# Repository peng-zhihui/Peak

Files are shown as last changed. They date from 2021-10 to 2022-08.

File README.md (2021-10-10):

## 说明

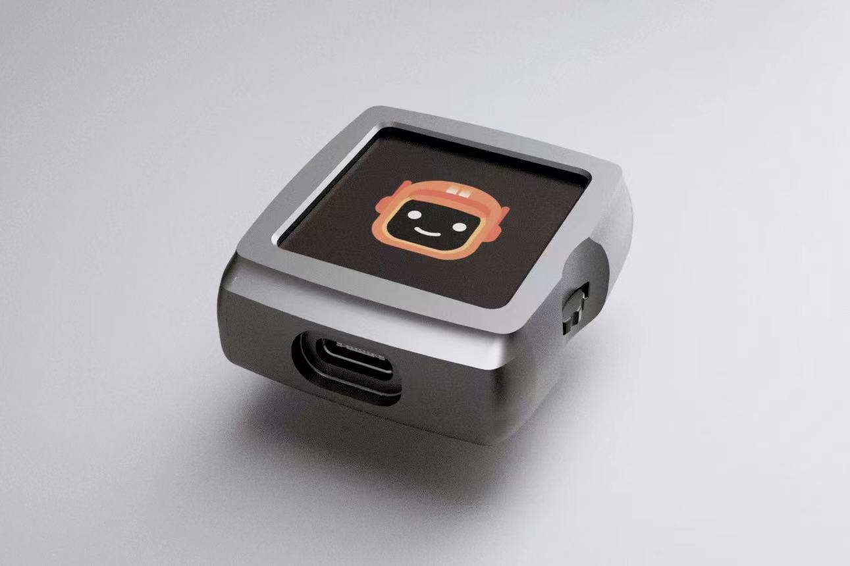
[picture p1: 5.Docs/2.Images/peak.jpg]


> 本项目是一个超迷你的智能小终端，集成LVGL图像框架、MVC框架、消息框架、WiFi蓝牙能力，未来会加入触摸屏支持。可以作为智能控制器用于实现很多应用。
>
> 另外我正在上面实现一个非常小型的3D引擎，可以用于动态显示一些3D模型（就像Dummy示教器中展示的那样）。

非常感谢 https://github.com/FASTSHIFT 开源的X-Track项目，本文是对于X-Track硬件和固件往ESP32平台移植的记录说明。

## 1. 硬件移植

### 关于芯片选型

主要考虑MCU的Flash、SRAM、SPI速度，需要满足以下要求：

* 主频 > 150MHz
* RAM >= 200KB
* FLASH >= 512KB
* SPI速度 >= 50Mbps（60fps刷新率的要求）

> lvgl中需要设置LCD buffer，一般设置为屏幕分辨率大小，在本项目中为240x240x2（因为是16bit色深所以每个像素2字节），算下来至少需要112KB的SRAM。
>
> SPI的CLK速度计算如下：240x240x2x8x60=55.296MHz，因此最好是达到50MHz以上的频率才能保证刷新流畅（实际上不使用DMA传输数据的话帧率会更低）。

经过筛选满足以上要求的MCU，综合考虑成本和购买渠道问题，除了官方项目使用的雅特力AT32F403ACGU7主控外，还有两款是比较合适的：STM32F405RGT6、ESP32。

**对比优缺点如下：**

* STM32F405的主频不如ESP32高且后者为双核；
* 外设方面STM32F405更丰富，也支持使用DMA+SPI驱动屏幕；
* ESP32带WiFi能力，STM32不带；
* ESP32可以直接基于Arduino生态开发，而STM32一般基于HAL库，移植Arduino较麻烦；
* STM32可以使用ST-Link方便调试而ESP32只能通过串口打印log调试。

最终选择**ESP32-PICO-D4**作为移植MCU方案。

## 2. 固件移植

原工程的架构分层设计比较合理，整体软件架构如下图所示，系统由 HAL、Framework 和 APP 三层组成 ：

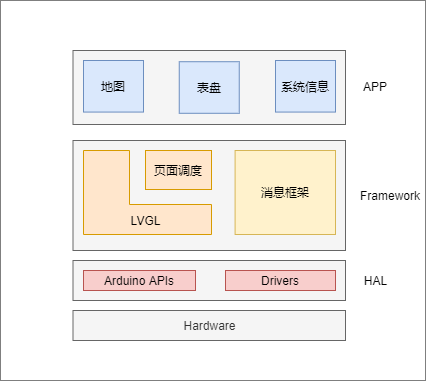
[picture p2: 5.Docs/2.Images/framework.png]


### LVGL 和页面调度

LVGL是开源的嵌入式图形库，其广泛应用嵌入式 GUI 中，提供了基础控件和底层图形渲染能力。

X-TRACK 使用 LVGL 作为图形库，提供用户显示界面，并使用了许多 LVGL 提供的基础控件。例如在地图页面的轨迹显示中使用了 line 控件，地图显示使用了 image 控件，在表盘页面的页面切换选择，使用了 button 控件。由于 LVGL 自带页面管理功能较弱，需要规范页面行为，便于对页面生命周期进行管理。

页面调度器参考 **IOS ViewController** 进行设计，页面生命周期管理流程图如下：

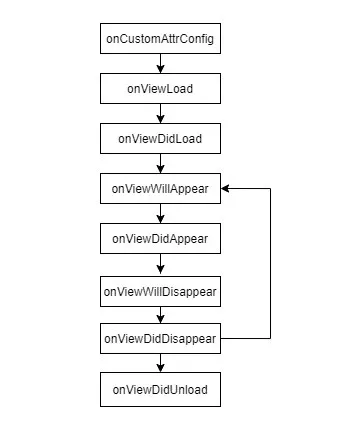
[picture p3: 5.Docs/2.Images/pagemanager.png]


根据页面当前状态，对页面动作进行管理。例如地图页面的加载，在执行 onViewLoad (页面开始加载)时初始化视图和数据；在 onViewDidAppear（页面即将显示） 执行过渡动画，在动画结束时显示地图容器。

在有外部按键事件触发后，依次执行onViewWillDisappear(页面即将消失)、 onViewDidDisappear （页面消失完成）、onViewDidUnload（页面卸载完成）。

### 消息框架

消息框架提供数据的分发和处理。其使用订阅发布机制完成，将 HAL 层的接收到的传感器数据发布，转发给对应的订阅者进行数据处理。

以 GPS 为例，GPS 数据处理节点每秒读取一次卫星数据，然后发起 publish ，由消息框架将 GPS 数据推送给订阅者。在运动数据处理节点中订阅 GPS 数据。在收到 GPS 数据之后，运动数据处理节点根据 GPS 数据计算总里程，平均速度等信息。在表盘页面中，拉取运动数据节点信息，将其显示在表盘页面中。

比如下图为 GPS 数据事件回调函数:

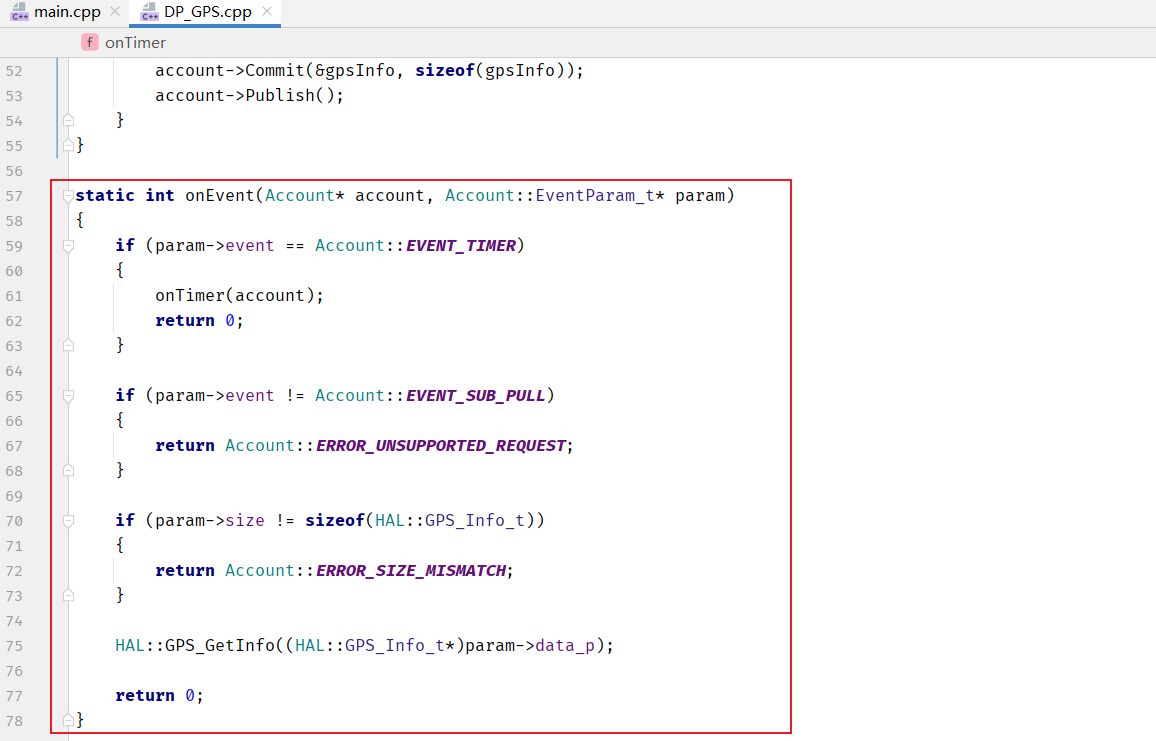
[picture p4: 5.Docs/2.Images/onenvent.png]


### 屏幕移植

具体移植步骤为：

1. 将LVGL（使用版本为`v8.1`）的相关port函数移植到新平台（显示、文件、输入）
2. 实现HAL层的各个文件

> 其中第一步中SD卡文件系统的移植遇到问题是用SD库可以读写，而LVGL的文件操作函数不行，后发现原因是`lv_port_fatfs.cpp`文件中的`lv_fs_drv_t fs_drv`变量需要改为全局/静态变量，原工程中在函数中声明static在CLion编译器下似乎不起作用。

显示的移植涉及到几个配置文件:`Config.h` 、`lv_conf.h`、`User_Setup_Select.h`（`Setup24_ST7789.h`）

首先根据屏幕型号使用`TFT_eSPI`库驱动测试好硬件。

> TFT_eSPI库速度比其他库快，而且其数据类型和LVGL无缝对接。

这个项目中选择`Setup24_ST7789.h`这个配置文件，除了**GPIO**、**屏幕反向**、**像素顺序**设置正确之外，`SPI_FREQUENCY`也是一个很重要的参数，如前面所计算的，为了是的屏幕刷新率达到60Hz，需要设置这个频率高于50MHz。

然而，对于ESP32来说，其具有2个可用的硬件SPI：**HSPI**和**VSPI**。

> SPI0是专用于Flash的缓存，ESP32将连接的SPI Flash设备映射到内存中；SPI1和SPI0 使用相同的硬件线，SPI1用于写入flash芯片。
>
> VSPI是默认的SPI总线，要使用HSPI的话，**需要修改以下代码中的MISO为26**：
>
> ```
>  if(sck == -1 && miso == -1 && mosi == -1 && ss == -1) {
>      _sck = (_spi_num == VSPI) ? SCK : 14;
>      _miso = (_spi_num == VSPI) ? MISO : 12; // 需要改为26
>      _mosi = (_spi_num == VSPI) ? MOSI : 13;
>      _ss = (_spi_num == VSPI) ? SS : 15;
> ```
>
> 这是因为，HSPI的默认MISO引脚是12，而12在ESP32中是用于上电时设置flash电平的，上电之前上拉会导致芯片无法启动，因此我们将默认的引脚替换为26或其他引脚。

由数据手册可知，ESP32的SPI时钟是由80MHz的`APB_CLK`时钟信号分频而来，因此最高支持的频率为80MHz，如果分频的话，库函数会自动选择分配系数来获得最接近于设定频率的整数倍系数。

> **注意**，只有在使用IOMUX时才能获得最高的SPI频率，如果SPI采用GPIO矩阵，则最大频率会限制在26.6MHz。
>
> IOMUX指的是不使用IO-Matrix的映射功能，而是使用默认的MISO、MOSI、CLK引脚，也就是如下图：
>
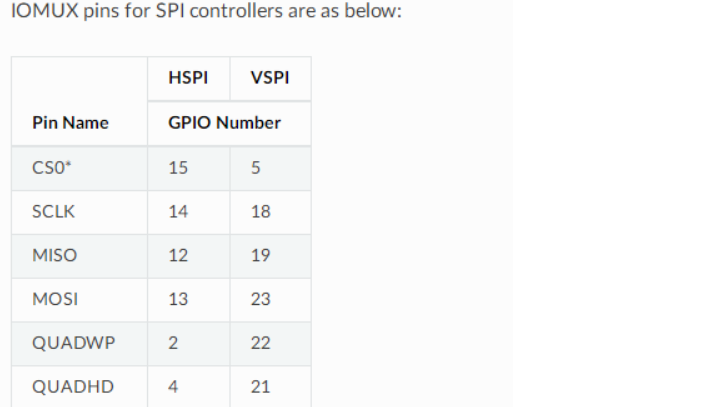
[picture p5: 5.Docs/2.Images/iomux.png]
> 

屏幕驱动验证完成后，配置LVGL的相关初始化函数，其中`lv_conf.h`的配置有几点值得注意的：

* **LV_MEM_SIZE的设置**

  在Arduino环境中LVGL默认定义LV_MEM_CUSTOM=0，即不使用标准库中的*malloc*等内存分配函数，而是封装了一个*lv_mem_alloc()*函数用于内存申请。这个函数的原理其实是**先在编译的时候申请一块`LV_MEM_SIZE`大小的数组内存，然后在后面使用*lv_mem_alloc()*函数的时候，从这块内存中进行分配。**

  因此，`LV_MEM_SIZE`设置的内存大小是在bss段分配的，**这个数值设置过大的话会导致编译链接阶段报错内存不足。**

  > 经测试设置16K就足够了，因此代码中该值为`(16 * 1024U)` 。
  >
  > 如果想在后面屏幕buffer中使用这块内存进行分配，那就需要设置大一点，但是ESP32的Arduino框架中对于申请静态内存的尺寸有限制，因此我们并不使用这里的内存，而是到时候用*malloc()*函动态数申请。

* **`lv_disp_draw_buf_init`函数中的屏幕buffer设置**

  这个buffer可以设置为单buffer或者双buffer，但是双buffer只在使用DMA传输数据的时候可以起作用（刷新缓存和传输数据并行），因此这里只用单buffer。

  理论上buffer的尺寸等于屏幕分辨率是最理想的，可以保证一次刷新整个屏幕，~~但是由于ESP32的内存大小限制，本代码中最大只能设置为屏幕分辨率的一半。~~

  > 最早HoloCubic的代码中并未注意到这一设置，buffer只设置为了240x10，因此导致画面刷新缓慢且有撕裂感。
  >
  > 关于ESP32内存申请的限制，由于能用的内存实际只有大概300KB，而屏幕完整buffer需要112KB，因此很难在内存中找到连续的那么大片空间，~~经测试不管是用静态变量申请还是malloc动态申请，都无法成功，因此只能设置为一半大小的buffer。~~
  >
  > 在ESP32-PICO-D4上测试发现，如果新建空白工程再用`ESP.getMaxAllocHeap()`，得到的可用空间是略大于115200B的，但是加入`lvgl_init()`代码之后就不足115200了，因此修改`lvgl_init()`函数代码，把`lv_mem_init`函数中static 变量申请的内存改为动态malloc，即可解决buffer问题。
  >
  > 引起该问题的原因是，ESP32有多块内存可以映射为dataRAM，总大小是300KB左右，但它们之间是不连续的，最大的一块刚好略大于115200。如果在代码中事先编译的时候分配内存占用了这一块（声明了static变量），或者运行的时候在LVGL申请屏幕buffer之前先被其他地方申请了该块内存导致连续可用heap小于115200，那么屏幕buffer就无法申请成功。因此解决方案是先在代码中将这块最大的heap申请下来给屏幕buffer，再运行其他初始化代码即可完美解决。
  
  关于ESP32的内存模型更多信息，可以参考文章末尾链接的几篇文章分析。

## 参考链接 

* [LVGL](https://github.com/lvgl/lvgl)
* [Bing Maps Tile System](https://docs.microsoft.com/en-us/bingmaps/articles/bing-maps-tile-system?redirectedfrom=MSDN)
* [IOS ViewController](https://developer.apple.com/documentation/uikit/uiviewcontroller)
* [ESP32之软件SPI驱动及SPI、HSPI和VSPI的理解](https://blog.csdn.net/jdsnpgxj/article/details/100013357)
* [ESP32 程序的内存模型](https://zhuanlan.zhihu.com/p/345915256)
* [Heap Memory Allocation](https://docs.espressif.com/projects/esp-idf/en/latest/esp32/api-reference/system/mem_alloc.html)
* [Error: region `dram0_0_seg' overflowed by 31632 bytes](https://www.esp32.com/viewtopic.php?t=7131)
* [[ESP32] ld: region `dram0_0_seg’ overflowed by 156768 bytes](https://community.platformio.org/t/esp32-ld-region-dram0-0-seg-overflowed-by-156768-bytes/18753)

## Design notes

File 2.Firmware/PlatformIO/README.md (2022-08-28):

Peak-ESP32-fw(6050)      修改9250程序为6050

上一个版本在最新的platformio框架会报FreeRTOS路径错误和sd库中定义错误

由于platformio框架版本问题会报的错误解决方法：

HAL.h 文件  \#include "FreeRTOS.h"改为 \#include "FreeRTOS/FreeRTOS.h"

lib/SD/src/sd_diskio.cpp   添加头文件 \#include "diskio_impl.h"

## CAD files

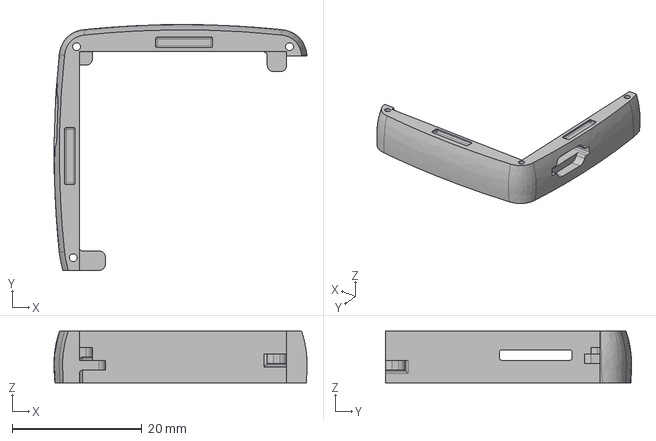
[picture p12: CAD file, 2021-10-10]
4.Model/侧件.step
38.9 x 37.8 x 8.00 mm

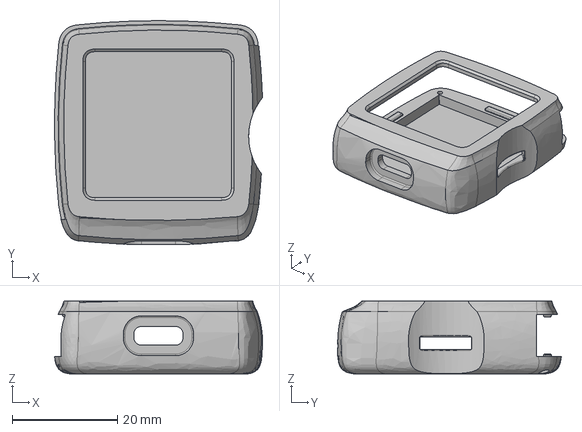
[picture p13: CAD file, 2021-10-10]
4.Model/主件.step
39.5 x 42.5 x 13.8 mm

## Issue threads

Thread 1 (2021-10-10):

关于元器件推荐咨询以及3D模型

zhiwenwu, 2021-10-10:
大佬，有推荐的元器件链接吗？还有大佬的3D建模用的是哪款软件吗？

peng-zhihui, 2021-10-10:
是说元器件库吗？我一般都是自己画的

peng-zhihui, 2021-10-10:
> 这个是8PIN接插屏幕吗？找了好长时间。有老铁有推荐链接吗？

https://detail.tmall.com/item.htm?id=607394513826&_u=a2hql9gc2718

mascg, 2021-10-10:
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

https://github.com/FASTSHIFT/X-TRACK/tree/main/Hardware
X-TRACK 用的这个屏幕，应该可以参考下

peng-zhihui, 2021-10-10:
就是上面这款

zhiwenwu, 2021-10-14:
> 就是上面这款
https://github.com/FASTSHIFT/X-TRACK/tree/main/Hardware
大佬，我按照这块屏幕购买的硬件，发现这款不是FFC/FPC接口的，请问您这8PIN的硬件，是有增加转接板吗？如果没有转接板的话，能帮忙看下具体购买链接？

Closed 2021-10-10.

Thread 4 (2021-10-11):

Peak硬件电路设计问题

captain-zhang, 2021-10-11:
彭兄好，今天看了peak的电路设计，我鸡蛋里面挑骨头，提点建议。在电源模块的设计中，锂电池充电芯片的输出既为锂电池充电，又为整个电路供电，这样设计会有问题。充电时既会影响电池端电压又会分充电电流，严重影响充电芯片对电池状态的判断。这种情况下锂电池一般无法充满电。因此设计中应该在外部供电时，切断电池与后续电路的连接，此时整个电路的供电应该由充电芯片的前端电源提供。

SuperWangRong, 2021-10-21:
> 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
>
> 这是我结合稚晖君的电路以及b站郭天祥老师的锂电池充电电路改动后的，是可以实现供电切换的，欢迎指正 郭天祥老师此部分电路视频链接：https://www.bilibili.com/video/BV17Q4y1k78s?spm_id_from=333.999.0.0

Q4和R7是不是可以去掉啊？

SuperWangRong, 2021-10-21:
> 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
>
> 这是我结合稚晖君的电路以及b站郭天祥老师的锂电池充电电路改动后的，是可以实现供电切换的，欢迎指正 郭天祥老师此部分电路视频链接：https://www.bilibili.com/video/BV17Q4y1k78s?spm_id_from=333.999.0.0

还有U1的3号脚应该接VCC_SYS吧？

SuperWangRong, 2021-11-02:
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
我实测发现CHG_DET处的上拉电阻为10K时无法将该点拉至3.3V，实测只有1.9V左右，此时MCU检测为低电平，显示屏的电池图标会为动态充电样式，将电阻改成1K上拉后，CHG_DET测量下来为2.5V左右，MCU检测为高电平，显示屏的电池图标状态为静止状态，这时显示是正确的，，，，，另外BAT_DET的分压电阻网络的电源我改成了VABT_IN，附图是我更新后的电路，可供后来人参考，如有错误或不完善处还请帮忙指出，多谢~

Purvirs, 2022-02-04:
> 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 我实测发现CHG_DET处的上拉电阻为10K时无法将该点拉至3.3V，实测只有1.9V左右，此时MCU检测为低电平，显示屏的电池图标会为动态充电样式，将电阻改成1K上拉后，CHG_DET测量下来为2.5V左右，MCU检测为高电平，显示屏的电池图标状态为静止状态，这时显示是正确的，，，，，另外BAT_DET的分压电阻网络的电源我改成了VABT_IN，附图是我更新后的电路，可供后来人参考，如有错误或不完善处还请帮忙指出，多谢~

----------------
多谢改进，根据手册和实际调试发现，73831在充电结束之后会拉高STAT脚，电压约等于VBUS-0.4，此时输入口灌入电压高于3.3V会造成AD采样工作不正常，对芯片的稳定工作也是一个影响。此处最好转换电平。

zhaoyang6, 2022-04-19:
关于73831在充电结束后，拉高STAT引脚，后输出电压约等于(VBUS-0.4)V，而ESP32的管脚电压最高是（VDD+0.3）V。在设计中使用的电池是VBUS=3.7V，VDD=3.3V,这样计算来，STAT引脚输出电压约是3.3V, 管脚电压最高是3.6V, 在这样小的差距下，是否可能会有损坏芯片的情况？

Purvirs, 2022-04-30:
> 关于73831在充电结束后，拉高STAT引脚，后输出电压约等于(VBUS-0.4)V，而ESP32的管脚电压最高是（VDD+0.3）V。在设计中使用的电池是VBUS=3.7V，VDD=3.3V,这样计算来，STAT引脚输出电压约是3.3V, 管脚电压最高是3.6V, 在这样小的差距下，是否可能会有损坏芯片的情况？

注意上述讨论，是基于做了电源自动切换，在充电时VBUS几乎等于USB供电电压，约为5V，实际灌入到ESP32电压是4点几伏。
针对这个问题不才改了一版仅供参考
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

geekfuns, 2022-08-17:
> 这里确实是一个设计失误，感谢指出

实际上使用一篇带动态路径管理的电源芯片就好了，在我的设计中使用了ETA6002，完全满足需求，自动切换主备电并且具备电池充电功能

juring, 2022-12-02:
> 73831在充电结束之后会拉高STAT脚，电压约等于VBUS-0.4，此时输入口灌入电压高于3.3V会造成AD采样工作不正常，对芯片的稳定工作也是一个影响。此处最好转换电平。

是不是换成 73832 就行了。

Purvirs, 2023-02-11:
>

换成17832也不能解决这个问题

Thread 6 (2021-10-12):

关于线程同步

zye1996, 2021-10-12:
Hi Zhihui, 目前我把固件移植到了m5stack上，运行还没有出现问题。

我看到ESP32这个版本是多线程的，lvgl事件循环单独在一个线程里轮询控件状态，page manager在loop线程也会创建删除控件，这样在复杂情况下需要做线程同步吗？

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

peng-zhihui, 2021-10-12:
是需要的，考虑使用FreeRTOS的信号量同步。

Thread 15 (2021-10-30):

请教一下，稚晖君你的开发环境是什么？

FlyyingPiggy2020, 2021-10-30:
不知道稚晖君，你是用什么IDE开发的ESP32程序？是在Windows平台还是别的平台？
我现在对着这份代码，不知道怎么去编译它。。

peng-zhihui, 2021-10-30:
了解一下platformio，windows下编译，安装好环境直接用vscode打开项目文件夹就能编译了

发自我的iPhone

------------------ 原始邮件 ------------------
发件人: BeeeeeeLazy ***@***.***&gt;
发送时间: 2021年10月30日 15:21
收件人: peng-zhihui/Peak ***@***.***&gt;
抄送: Subscribed ***@***.***&gt;
主题: 回复：[peng-zhihui/Peak] 请教一下，稚晖君你的开发环境是什么？ (Issue #15)

Closed 2023-11-14.

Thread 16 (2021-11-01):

关于CON1 引脚引出问题

HanfG, 2021-11-01:
MCU的 GPIO5, GPIO10, GPIO19, GPIO32, GPIO33 五个引脚由CON1引出，其中GPIO32, 33已被I2C总线使用，目前线上有MPU6050，引出可以用于I2C 设备扩展；其余3个IO引脚应该是用于普通IO扩展吧，我看到芯片的GPIO9目前是悬空状态，是不是可以考虑用GPIO9替换GPIO5吗？这样可以实现MCU的UART 1信号引出 增强扩展性，也可以避免意外情况下GPIO5拉低导致MCU无法正常启动。
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

peng-zhihui, 2021-11-01:
esp32是带gpio-matrix的，差不多所有引脚都能自由映射

发自我的iPhone

------------------ 原始邮件 ------------------
发件人: HanfG ***@***.***&gt;
发送时间: 2021年11月1日 16:47
收件人: peng-zhihui/Peak ***@***.***&gt;
抄送: Subscribed ***@***.***&gt;
主题: 回复：[peng-zhihui/Peak] 关于CON1 引脚引出问题 (Issue #16)

MCU的 GPIO5, GPIO10, GPIO19, GPIO32, GPIO33 五个引脚由CON1引出，其中GPIO32, 33已被I2C使用，目前线上由MPU6050，引出可以用于I2C 设备扩展；其余3个IO引脚应该是用于普通IO扩展吧，芯片的GPIO9目前是悬空状态，可以考虑用GPIO9替换GPIO5吗？这样可以实现MCU的UART 1信号引出 增强扩展性，也可以避免意外情况下GPIO5拉低导致MCU无法正常启动。

—
You are receiving this because you are subscribed to this thread.
Reply to this email directly, view it on GitHub, or unsubscribe.
Triage notifications on the go with GitHub Mobile for iOS or Android.

HanfG, 2021-11-01:
好的，学到了，感谢> esp32是带gpio-matrix的，差不多所有引脚都能自由映射
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

Closed 2021-11-02.

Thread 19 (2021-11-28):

页面切换到3D 正方形后回不了SystemInfos页面

bt5-coder, 2021-11-28:
zhihui你好，

感谢你的创作和工作，我已经把软件移植到M5 Stack，目前遇到一个小问题，不知道是不是一个Bug。
页面管理从SystemInfos 切到 Scene 3D在切回到SystemInfos， 再次按下按钮切到 Scene 3D之后，无论怎么操作都切不回SystemInfos 界面，界面一直是Sense 3D的图像，但此时按键log告诉我已经在SystemInfos even里面了。

我单独拉出template和Scene 3D，按照Push - > Pop操作，一样存在问题 ，切一次页面后，停留在template，无法再切入Scene 3D。
不知道是不是页面管理的框架有问题。
本来想再模拟器上来验证，编译了你的代码，好多问题，应该是路径有问题。

以上信息供你参考。

bt5-coder, 2021-12-05:
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
我在模拟器上也可以复现，错误显示见上图。

spdffxyp, 2023-09-26:
最近也遇到了整个问题，解决方案如下：

在Scene3DView::Create函数中删除
lv_indev_set_group(lv_get_indev(LV_INDEV_TYPE_ENCODER), ui.group);

在Scene3D::onViewWillAppear函数中增加
lv_indev_set_group(lv_get_indev(LV_INDEV_TYPE_ENCODER), View.ui.group);

zhihui的Scene3D类是个半成品，里面还有别的坑，还在学习中。

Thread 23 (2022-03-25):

采用httpCilent获取天气状况的问题

pockrt-m, 2022-03-25:
在复现peak项目时发现，设备能够成功连接wifi，但获取天气时报错：
`_handle_error(): [start_ssl_client():205]: (-32512) SSL - Memory allocation failed`；
将屏幕分得的缓存尽可能减小后又能成功获取天气数据，判断可能是内存分配问题导致无法正常进行ssl_cilent，但不知道该如何进行修改，请各位大佬提提意见~

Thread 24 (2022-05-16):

下载的工程编译后报错，提示没有freertos文件 还有fat文件系统也有错误。

givemethree, 2022-05-16:
1.freertos  报错内容
******************************************************************

 #include "FreeRTOS.h"
          ^~~~~~~~~~~~
compilation terminated.
In file included from src/App/Accounts/ACT_IMU.cpp:2:
src/HAL/HAL.h:9:10: fatal error: FreeRTOS.h: No such file or directory

2.注释freertos文件后编译报fat 错误。

lib/SD/src/sd_diskio.cpp:825:18: error: 'ff_diskio_impl_t' does not name a type
     static const ff_diskio_impl_t sd_impl = {
                  ^~~~~~~~~~~~~~~~
lib/SD/src/sd_diskio.cpp:832:31: error: 'sd_impl' was not declared in this scope
     ff_diskio_register(pdrv, &sd_impl);
                               ^~~~~~~
lib/SD/src/sd_diskio.cpp:832:31: note: suggested alternative: 'fdiml'
     ff_diskio_register(pdrv, &sd_impl);
                               ^~~~~~~
                               fdiml
lib/SD/src/sd_diskio.cpp:832:5: error: 'ff_diskio_register' was not declared in this scope
     ff_diskio_register(pdrv, &sd_impl);
     ^~~~~~~~~~~~~~~~~~
lib/SD/src/sd_diskio.cpp:832:5: note: suggested alternative: 'lv_disp_drv_register'
     ff_diskio_register(pdrv, &sd_impl);
     ^~~~~~~~~~~~~~~~~~
     lv_disp_drv_register
*** [.pio\build\pico32\libbbe\SD\sd_diskio.cpp.o] Error 1

givemethree, 2022-05-21:
platform 安装方式的问题，重新按照标准安装方式安装platformio后 再编译就没问题了
标准安装方式： https://blog.csdn.net/JR_Smmon/article/details/120856365

givemethree, 2022-05-21:
问题关闭

jiuwei000, 2022-06-18:
> platform 安装方式的问题，重新按照标准安装方式安装platformio后 再编译就没问题了 标准安装方式： https://blog.csdn.net/JR_Smmon/article/details/120856365

我遇到了和你一样的问题，请问解决的关键点就是按这篇博文写的那样做么？我照着做了之后仍然报错没有freertos头文件。。。

FChong96, 2022-08-04:
我也遇到了相同的问题，缺少头文件，如果注释掉的话会出fat 错误。重装了Platform并没有解决问题。

jiuwei000, 2022-08-04:
>

问题解决了，esp32的platform用3.5版本

FChong96, 2022-08-04:
> >
>
> 问题解决了，esp32的platform用3.5版本
我也试一下，freertos头文件需要注释掉吗

MXuanZero, 2022-08-22:
> >
>
> 解决了，esp32的平台问题用3.5版本

请教一下，怎么安装3.5版本？我没找到相关的安装途径。
谢谢！

MXuanZero, 2022-08-22:
问题解决了，上面的解决方法试了一遍不太行，如果有人没解决的话可以去看我这个[issues](https://github.com/peng-zhihui/Peak/issues/28#issuecomment-1222158709)。
https://github.com/peng-zhihui/Peak/issues/28#issuecomment-1222158709

Closed 2022-05-21.

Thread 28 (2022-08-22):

请教一下各位，VS Code 打开工程后找不到 FreeRTOS.h 该怎么解决？

MXuanZero, 2022-08-22:
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
如图，VS Code 打开工程后找不到 FreeRTOS.h 文件，这是环境的问题吗？我该怎么解决？

另外，我用 CLion 编译项目时发生了如下错误。感觉我的 PlatformIO 好像少了什么文件一样，但我重装了两三次都存在这个问题？请问有办法解决吗？
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

MXuanZero, 2022-08-22:
花了一下午时间终于解决了，我们将以下代码复制到 diskio.h 的第 12 行。这个地方最初应该只有一行 `typedef BYTE DSTATUS;`。

```c
/* Status of Disk Functions */
/* This type MUST be 8 bit */
typedef unsigned char	BYTE;
typedef BYTE			DSTATUS;	//最初
/* These types MUST be 16 bit */
typedef short			SHORT;
typedef unsigned short	WORD;
typedef unsigned short	WCHAR;

/* These types MUST be 16 bit or 32 bit */
typedef int				INT;
typedef unsigned int	UINT;

/* These types MUST be 32 bit */
typedef long			LONG;
typedef uint32_t		DWORD;
```

**补充1：**倘若无法找到 FreeRTOS.h，我们只是要将工程中出现 FreeRTOS.h 的地方改成 freertos/FreeRTOS.h 就行了。

**补充2：**倘若出现类似于 error: 'ff_diskio_get_drive' was not declared in this scope 这种 FATFS 系统的函数找不到的错误。我们要将 \#include "diskio_impl.h" 添加到 sd_diskio.cpp 中。

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

==**请注意：**以上方法虽然可以成功编译，但我并没有烧到板子上去，所以也不知道能不能成！如果有人成功的话麻烦告知一下。==

MXuanZero, 2022-08-22:
花了一下午时间终于解决了，我们将以下代码复制到 diskio.h 的第 12 行。这个地方最初应该只有一行 `typedef BYTE DSTATUS;`。

```c
/* Status of Disk Functions */
/* This type MUST be 8 bit */
typedef unsigned char	BYTE;
typedef BYTE			DSTATUS;	//最初
/* These types MUST be 16 bit */
typedef short			SHORT;
typedef unsigned short	WORD;
typedef unsigned short	WCHAR;

/* These types MUST be 16 bit or 32 bit */
typedef int				INT;
typedef unsigned int	UINT;

/* These types MUST be 32 bit */
typedef long			LONG;
typedef uint32_t		DWORD;
```

**补充1：**倘若无法找到 FreeRTOS.h，我们只是要将工程中出现 FreeRTOS.h 的地方改成 freertos/FreeRTOS.h 就行了。

**补充2：**倘若出现类似于 error: 'ff_diskio_get_drive' was not declared in this scope 这种 FATFS 系统的函数找不到的错误。我们要将 \#include "diskio_impl.h" 添加到 sd_diskio.cpp 中。

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

==**请注意：**以上方法虽然可以成功编译，但我并没有烧到板子上去，所以也不知道能不能成！如果有人成功的话麻烦告知一下。==

LiangTY, 2022-08-27:
DSTATUS、DWORD等问题，可以把#include "ff.h"放在#include "diskio.h"前面，让ff.h先编译即可。
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

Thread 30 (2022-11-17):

有没有遇到过这个问题朋友，[ 1316][E][esp32-hal-ledc.c:75] ledcSetup(): ledc setup failed!

compilerM, 2022-11-17:
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

0clock, 2023-02-10:
我也遇到了相同的问题：
```
rst:0xb (TGWDT_CPU_RESET),boot:0x1b (SPI_FAST_FLASH_BOOT)
configsip: 188777542, SPIWP:0xee
clk_drv:0x00,q_drv:0x00,d_drv:0x00,cs0_drv:0x00,hd_drv:0x00,wp_drv:0x00
mode:DIO, clock div:2
load:0x3fff0030,len:1184
load:0x40078000,len:13132
load:0x40080400,len:3036
entry 0x400805e4
[littleVisual]
Version: v1.0
Author: PZH
Power: Waiting...
Power: ON
E (1024) ledc: freq_hz=0 duty_resolution=8
[  1028][E][esp32-hal-ledc.c:75] ledcSetup(): ledc setup failed!
[  1029][E][esp32-hal-gpio.c:102] __pinMode(): Invalid pin selected
E (1029) gpio: gpio_set_level(226): GPIO output gpio_num error
[  1039][E][esp32-hal-gpio.c:102] __pinMode(): Invalid pin selected
E (1041) gpio: gpio_set_level(226): GPIO output gpio_num error
[Warn]	(1.620, +1620)	 lv_init: Style sanity checks are enabled that uses more RAM 	(in lv_obj.c line #163)
```

jxltom, 2023-09-06:
屏幕能点亮吗？

zhaoc9527, 2023-11-28:
我也遇到了，屏幕没反应 怎么办呢

zhaoc9527, 2023-11-29:
> 在paltforformio.ini 文件中指定使用3.5.0的版本 platform = espressif32@~3.5.0

谢谢，这个错误好了 屏幕不亮，报错[Error] (1.477, +1477)   sdcard_mount: f_mount failed: (13) There is no valid FAT volume

SD卡使FAT32格式的，16GB

请问这个使什么原因呢

zhaoc9527, 2023-11-29:
![Uploading 微信图片_20231129115343.png…]()

zhaoc9527, 2023-11-29:
![Uploading 微信图片_20231129115343.png…]()

txp666, 2023-11-29:
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

[littleVisual-ESP32-fw(6050).zip](https://github.com/peng-zhihui/Peak/files/13496020/littleVisual-ESP32-fw.6050.zip)
用这个程序，有问题的话请检查硬件焊接或者sd卡

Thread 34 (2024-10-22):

IntegerDivideByZero导致的系统崩溃重启问题

Raphtalia-chann, 2024-10-22:
稚晖君您好！想请教一下在切换页面时经常会出现IMU错误：
`[E][esp32-hal-i2c.c:1434] i2cCheckLineState(): Bus Invalid State, TwoWire() Can't init sda=1, scl=1`
检查焊接应该没有问题，停在IMU或其他任何页面不动又不会报错，但出现这个报错一般伴随着
`Guru Meditation Error: Core  0 panic'ed (IntegerDivideByZero). Exception was unhandled.`
直接导致系统崩溃重启，使用的是MPU6050，以下是完整错误日志：
```
[E][esp32-hal-i2c.c:1434] i2cCheckLineState(): Bus Invalid State, TwoWire() Can't init sda=1, scl=1
[E][esp32-hal-i2c.c:1434] i2cCheckLineState(): Bus Invalid State, TwoWire() Can't init sda=1, scl=1
[E][esp32-hal-i2c.c:1434] i2cCheckLineState(): Bus Invalid State, TwoWire() Can't init sda=1, scl=1
Guru Meditation Error: Core  0 panic'ed (IntegerDivideByZero). Exception was unhandled.
Core 0 register dump:
PC      : 0x400d3140  PS      : 0x00060130  A0      : 0x800d2d1b  A1      : 0x3fffbbb0
A2      : 0x3ffdf7b8  A3      : 0x3ffdbd2c  A4      : 0x000000ed  A5      : 0x0000006e
A6      : 0x00000000  A7      : 0x00000040  A8      : 0x00003fff  A9      : 0xffff5884
A10     : 0x00000000  A11     : 0xfff3f475  A12     : 0xfffff3c0  A13     : 0x3f40054c
A14     : 0x3ffdf844  A15     : 0x00000008  SAR     : 0x0000000a  EXCCAUSE: 0x00000006
EXCVADDR: 0x00000000  LBEG    : 0x400d30c0  LEND    : 0x400d3152  LCOUNT  : 0x00000001

ELF file SHA256: 0000000000000000

Backtrace: 0x400d3140:0x3fffbbb0 0x400d2d18:0x3fffbc90 0x400d2d25:0x3fffbcb0 0x400e8646:0x3fffbcd0 0x400d78e7:0x3fffbd00 0x4009099a:0x3fffbd20
```

Rebooting...

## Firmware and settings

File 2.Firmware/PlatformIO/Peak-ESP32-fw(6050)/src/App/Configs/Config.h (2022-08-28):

#ifndef __CONFIG_H
#define __CONFIG_H

/*=========================
   Application configuration
 *=========================*/

#define CONFIG_SYSTEM_SAVE_FILE_PATH          "S:/SystemSave.json"
#define CONFIG_SYSTEM_LANGUAGE_DEFAULT        {'e','n','-','G','B'}
#define CONFIG_SYSTEM_GMT_OFFSET_DEFAULT      8 // GMT+ 8

#define CONFIG_WEIGHT_DEFAULT                 65 // kg

#define CONFIG_GPS_REFR_PERIOD                1000 // ms
#define CONFIG_GPS_LNG_DEFAULT                116.391332
#define CONFIG_GPS_LAT_DEFAULT                39.907415

#define CONFIG_TRACK_FILTER_OFFSET_THRESHOLD  2 // pixel
#define CONFIG_TRACK_RECORD_FILE_DIR_NAME     "Track"

#define CONFIG_MAP_USE_WGS84_DEFAULT          false

#define CONFIG_MAP_DIR_PATH                   {'/','M','A','P'}//"/MAP"

#define CONFIG_ARROW_THEME_DEFAULT            "default"

#define CONFIG_LIVE_MAP_LEVEL_DEFAULT         16
#define CONFIG_LIVE_MAP_VIEW_WIDTH            LV_HOR_RES
#define CONFIG_LIVE_MAP_VIEW_HEIGHT           LV_VER_RES

/* Simulator */
#define CONFIG_TRACK_VIRTUAL_GPX_FILE_PATH    "S:/TRK_20210801_203324.gpx"

/*=========================
   Hardware Configuration
 *=========================*/

#define NULL_PIN                    PD0

/* Screen */
#define CONFIG_SCREEN_CS_PIN        PB0
#define CONFIG_SCREEN_DC_PIN        PA4
#define CONFIG_SCREEN_RST_PIN       PA6
#define CONFIG_SCREEN_SCK_PIN       PA5
#define CONFIG_SCREEN_MOSI_PIN      PA7
#define CONFIG_SCREEN_BLK_PIN       12

#define CONFIG_SCREEN_HOR_RES       240
#define CONFIG_SCREEN_VER_RES       240
#define CONFIG_SCREEN_BUFFER_SIZE   (CONFIG_SCREEN_HOR_RES * CONFIG_SCREEN_VER_RES /2)

/* Battery */
#define CONFIG_BAT_DET_PIN          37
#define CONFIG_BAT_CHG_DET_PIN      38

/* Buzzer */
#define CONFIG_BUZZ_PIN             25
#define CONFIG_BUZZ_CHANNEL         2
#define CONFIG_SOUND_ENABLE_DEFAULT true

/* IMU */
#define CONFIG_IMU_INT1_PIN         32
#define CONFIG_IMU_INT2_PIN         33

/* I2C */
#define CONFIG_MCU_SDA_PIN          32
#define CONFIG_MCU_SCL_PIN          33

/* Encoder */
#define CONFIG_ENCODER_B_PIN        34
#define CONFIG_ENCODER_A_PIN        35
#define CONFIG_ENCODER_PUSH_PIN     27

/* Power */
#define CONFIG_POWER_EN_PIN         21

/* Debug USART */
#define CONFIG_DEBUG_SERIAL         Serial

/* SD CARD */
#define CONFIG_SD_SPI               SPI_SD
#define CONFIG_SD_CD_PIN            -1
#define CONFIG_SD_MOSI_PIN          PB15
#define CONFIG_SD_MISO_PIN          PB14
#define CONFIG_SD_SCK_PIN           PB13
#define CONFIG_SD_CS_PIN            15
#define CONFIG_SD_DET_PIN           22

/* Stack Info */
#define CONFIG_USE_STACK_INFO       0

#endif

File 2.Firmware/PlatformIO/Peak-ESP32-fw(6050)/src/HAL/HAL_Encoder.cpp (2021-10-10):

#include "HAL/HAL.h"
#include "App/Utils/ButtonEvent/ButtonEvent.h"
#include "App/Accounts/Account_Master.h"

static ButtonEvent EncoderPush(5000);

static bool EncoderEnable = true;
static volatile int16_t EncoderDiff = 0;
static bool EncoderDiffDisable = false;

Account* actEncoder;

static void Encoder_IrqHandler()
{
    if (!EncoderEnable || EncoderDiffDisable)
    {
        return;
    }

    static volatile int count, countLast;
    static volatile uint8_t a0, b0;
    static volatile uint8_t ab0;
    uint8_t a = digitalRead(CONFIG_ENCODER_A_PIN);
    uint8_t b = digitalRead(CONFIG_ENCODER_B_PIN);
    if (a != a0)
    {
        a0 = a;
        if (b != b0)
        {
            b0 = b;
            count += ((a == b) ? 1 : -1);
            if ((a == b) != ab0)
            {
                count += ((a == b) ? 1 : -1);
            }
            ab0 = (a == b);
        }
    }

    if (count != countLast)
    {
        EncoderDiff += (count - countLast) > 0 ? 1 : -1;
        countLast = count;
    }
}

static void Encoder_PushHandler(ButtonEvent* btn, int event)
{
    if (event == ButtonEvent::EVENT_PRESSED)
    {
        HAL::Buzz_Tone(500, 20);
        EncoderDiffDisable = true;
    } else if (event == ButtonEvent::EVENT_RELEASED)
    {
        HAL::Buzz_Tone(700, 20);
        EncoderDiffDisable = false;
    } else if (event == ButtonEvent::EVENT_LONG_PRESSED)
    {
        HAL::Audio_PlayMusic("Shutdown");
        HAL::Power_Shutdown();
    }
}

static void Encoder_RotateHandler(int16_t diff)
{
    HAL::Buzz_Tone(300, 5);

    actEncoder->Commit((const void*) &diff, sizeof(int16_t));
    actEncoder->Publish();
}

void HAL::Encoder_Init()
{
    pinMode(CONFIG_ENCODER_A_PIN, INPUT_PULLUP);
    pinMode(CONFIG_ENCODER_B_PIN, INPUT_PULLUP);
    pinMode(CONFIG_ENCODER_PUSH_PIN, INPUT_PULLUP);

    attachInterrupt(CONFIG_ENCODER_A_PIN, Encoder_IrqHandler, CHANGE);

    EncoderPush.EventAttach(Encoder_PushHandler);


    actEncoder = new Account("Encoder", AccountSystem::Broker(), sizeof(int16_t), nullptr);

}

void HAL::Encoder_Update()
{
    EncoderPush.EventMonitor(Encoder_GetIsPush());
}

int16_t HAL::Encoder_GetDiff()
{
    int16_t diff = -EncoderDiff / 2;
    if (diff != 0)
    {
        // EncoderDiff是实际的脉冲数；把本次变量用掉了，需要重新置0
        EncoderDiff = 0;
        Encoder_RotateHandler(diff);
    }

    return diff;
}

bool HAL::Encoder_GetIsPush()
{
    if (!EncoderEnable)
    {
        return false;
    }

    return (digitalRead(CONFIG_ENCODER_PUSH_PIN) == LOW);
}

void HAL::Encoder_SetEnable(bool en)
{
    EncoderEnable = en;
}

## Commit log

2021-10-10 Init repo.
    [Main.SchDoc, Peak.PrjPCB]
2021-10-10 [3D] Add step model.
    [主件.step, 侧件.step]
2022-08-27 9250->6050 适配最新Platform框架
